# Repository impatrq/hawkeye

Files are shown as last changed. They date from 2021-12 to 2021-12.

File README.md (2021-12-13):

<div align="center">
  
  

</div>

## ¿Que es Hawkeye?
  **Hawkeye** es un sistema desarrollado para asistir a la detección temprana de focos de incendios forestales a través del patrullaje de una flota de drones autónomos.

## ¿De donde surje Hawkeye?
  Este nace de la excesiva cantidad de territorio argentino incendiado el año pasado (2020), el cual superaba las **1.1 millones de hectareas**.
  
## ¿Como Funciona Hawkeye?
  Gracias a un sistema de transimision de datos via **Wi-Fi**, sus multiples **sensores** y su eficaz **aplicacion Android**. Todos estos se combinan de forma correcta para transmitir al usuario la alerta de fuego de la forma mas rapida posible.
  
## Reconocimientos
  Orgullosos de haber ganado el 🥈2do lugar🥈 en la competencia **PROAMBIENTE** de la Universidad Blas Pascal
  Certificado

## Contactanos
  * 📷 Instagram ➔ [Hawkeye Project](https://www.instagram.com/hawkeye.project/)
  * 🖥 Pagina Web ➔ [https://hawkeye-project.glitch.me/](https://hawkeye-project.glitch.me/)
  * ▶️ YouTube ➔ [Hawkeye Project](https://www.youtube.com/channel/UCOA-7zA83bXrav8Rf2SUFfQ)
  * 📧 Correo ➔ hawkeyeproyectimpa@gmail.com

**Desarrolladores:**
  - Garabato, Franco ➔ 📧 Correo: garabato1069@gmail.com
                     ➔ 📷 Instagram: [fran_garabato](https://www.instagram.com/fran_garabato/)
  - Orellano, Uriel ➔ 📧 Correo: uriel.ore9@gmail.com
                    ➔ 📷 Instagram: [awsxyz](https://www.instagram.com/awsxyz/)
  - Palacios, Zhang Lin ➔ 📧 Correo: zlpalacios@hotmail.com
                        ➔ 📷 Instagram: [zhanglinpalacios](https://www.instagram.com/zhanglinpalacios/)
  - Sala, Agustín ➔ 📧 Correo: agustinsala-maxi@outlook.com
                  ➔ 📷 Instagram: [agus_maxi_sala](https://www.instagram.com/agus_maxi_sala/)
  - Solís, Nicolás ➔ 📧 Correo: nikoletto777760@gmail.com
                   ➔ 📷 Instagram: [niko_solis9](https://www.instagram.com/niko_solis9/)
  - Villaescusa, Valentino ➔ 📧 Correo: gannival13@gmail.com
                           ➔ 📷 Instagram: [valen.uwu.18](https://www.instagram.com/valen.uwu.18/)

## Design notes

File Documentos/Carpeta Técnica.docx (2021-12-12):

Proyecto Hawkeye

Carpeta técnica

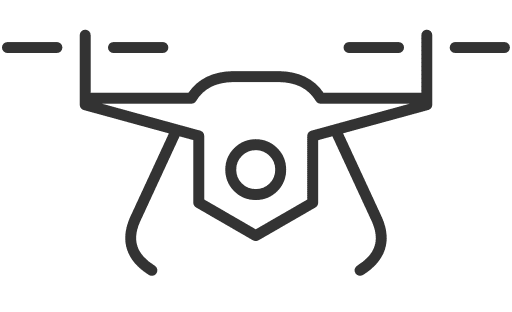
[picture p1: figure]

E.E.S.T. N°7 “IMPA”

Integrantes:

- Garabato, Franco Sicnic
- Orellano, Uriel
- Palacios, Zhang Lin Daoiz
- Sala, Agustin Maximilliano
- Solis, Nicolas
- Villaescusa, Valentino

Profesores a cargo:

- Bianco, Carlos Cesar
- Medina, Sergio
- Carlasara, Fabrizio
- Züge, Magalí
- Alegre, Marcos

Índice:

1. Introducción

1.1: Objetivo del proyecto

1.2: Descripción general

1.3: Diagrama en bloques

1.4: Funcionamiento

2. Componentes:

2.1: Microcontrolador ESP32
2.2: Bateria LiPo

2.3: Motores Brushless

2.4: Módulo GPS

2.5: Sensores MQ

2.6: Cámara térmica

2.7: Módulo transceptor NRF24L0

3. Software:

3.1: Arduino
3.2: Proteus

3.3: AutoCAD 3D

3.4: Cura WEEDO

3.5: Android Studio

4. Modelos 3D:

4.1: Introducción

4.2: Diseño completo del dron

5. Circuitos y plaquetas:

5.1: Placa de recolección de datos y transmisión del Drone
5.2: Placa de recepción y decodificación

5.3: Baliza de Localización Auxiliar

Introducción

1.1: Objetivos del proyecto

Sistema de detección prematura de focos de incendio

Es un proyecto totalmente diseñado y construido por los alumnos, utiliza un drone como plataforma para transportar sensores que sensan y detectan en forma temprana focos de incendio en bosques, sierras y reservas forestales con la finalidad de combatirlos en forma temprana para evitar incrementos en su letalidad y propagación.

A tal efecto se utilizaron sensores de Co, Co2, humo así como también cámaras para visualizar los focos de incendio.

Conforman una red de patrullaje y se utilizan balizas Receptoras-Transmisoras de las señales de alerta que se recuperan de los sensores.

De esta forma, se alerta e informa sobre el estado a un guardia o controlador a cargo de supervisar el escuadrón de drones, con el fin de fomentar la protección del medio ambiente, previendo posibles incendios y ayudando a los especialistas con un reconocimiento previo de la zona e información valiosa sobre la situación.

1.2: Descripción general

El proyecto Hawkeye fue diseñado y llevado a cabo por alumnos del IMPA. Se logró llevar a cabo un prototipo de uno de los drones que formarán parte de la flota vigilante, cuya estructura consta de una parte impresa en 3D y otra hecha en fibra de carbono. Utiliza una placa controladora (programada en Cleanflight) de la marca E-Flight, la cual controla los rotores del mismo por un protocolo PWM a una frecuencia de 50Hz. La placa actúa según lo que recibe por 5 canales de entrada (potencia, Pitch, Roll, Yaw y canal de control) los cuales funcionan con el mismo protocolo. Lo que se realizó para hacer el dron autónomo fue poner un paso antes de entregar los valores que da el receptor de RF. Antes de la placa Skymaster 32 se encuentran un sistema de control de automatización o vuelo manual y un ESP32 encargado de generar los pulsos PWM de acuerdo a la dirección que debe tomar el dron, siguiendo como referencia su localización geográfica, altitud y ángulo de incidencia.

En el modo manual se utiliza una radio RC de 2.4GHz, utilizada en aeromodelismo. En el modo autónomo, en cambio, el dron escucha al ESP32 el cual recibe las coordenadas de destino desde la aplicación de celular. Una vez recibida, las compara con sus coordenadas actuales (gracias a su módulo GPS) mediante algoritmos complejos, y dirige el dron a las nuevas coordenadas, teniendo de referencia su velocidad, altitud y ángulo de incidencia.

1.3: Diagrama en bloques

Transmisor del dron

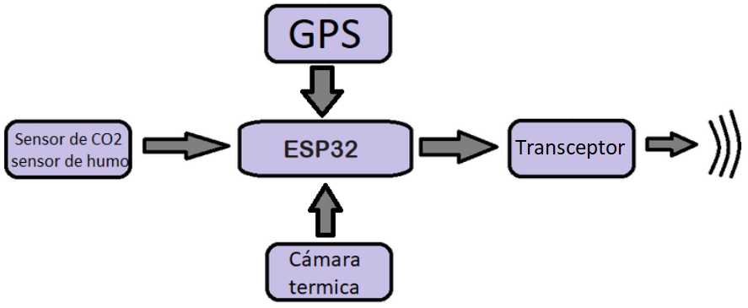
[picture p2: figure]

Receptor de tierra

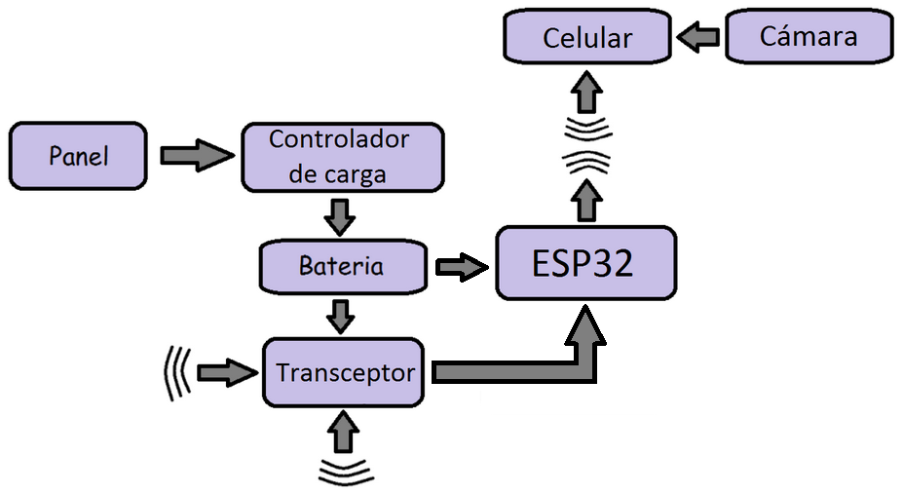
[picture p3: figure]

1.4: Funcionamiento Básico

El funcionamiento del dron es muy complejo, debido a esto lo dividimos en varios sectores:

- Funcionamiento del selector de modo (Manual y Autónomo)

Por medio de un transistor y el ESP32 es posible saturarlo o ponerlo en estado de corte para permitir o no el control a través de la radio RC. De esta forma, se puede seleccionar si recibe la información de control desde un micro, o desde la radio.

- Funcionamiento del sistema GPS

El sistema GPS es utilizado para saber datos como: el rumbo, altitud, velocidad y posición geográfica del dron. Esto nos sirve para que el operario tenga mayor control sobre el dron, para conocer la ubicación de los focos de incendio detectados y para designar el área de trabajo de la flota de drones.

- Funcionamiento del magnetómetro, giróscopo y acelerómetro

El magnetómetro indica la posición del eje longitudinal del drone con respecto al norte magnético y así saber hacia qué dirección debe dirigirse el dron. El giróscopo y acelerómetro se usan para corregir el efecto TILT.8.

- Funcionamiento del sistema de aterrizaje

Cuando se quiera aterrizar, se inicia el protocolo de aterrizaje, se detectará la distancia entre el dron y el suelo y si está en el rango ultrasónico el dron empieza a disminuir la altura lentamente y al aproximarse a unos 5cm-15cm al suelo apagará los motores lentamente para lograr un aterrizaje lo menos forzoso posible.

- Funcionamiento de la comunicación

Se utilizan 2 ESP32 para realizar la comunicación entre el dron y la app en tierra. El ESP en el drone posee un módulo transceptor NRF2401 a 2.4GHz el cual se comunicará con otro igual en tierra. El ESP en tierra recibe los datos del drone por medio del transceptor y luego los transmite por una red wifi que genera a un celular, con una aplicación especialmente diseñada para interpretarlos y mostrarlos al usuario. Los transceptores poseen un rango de funcionamiento de entre 1Km y 1.5Km, con una frecuencia de funcionamiento de 2.4GHz y capacidad telemétrica.

- Funcionamiento del sistema de detección de fuego

El sistema de detección de fuego consta de una serie de sensores capaces de detectar la presencia de un foco en diversas circunstancias. El sensor más obvio es uno de humo, cuyo objetivo no requiere mucha explicación. El segundo es un sensor de Co2, cuyo objetivo es detectar desbalances en el aire en lo que a partes por millón de Co2 respecta, y así poder presuponer la presencia de fuego. Por último, se posee una cámara termográfica, capaz de diferenciar calor a través de varios obstáculos, diurna o nocturnamente.

- Funcionamiento del sistema de avisos

En caso de detectar la presencia de fuego, automáticamente se envía una señal de alerta a la aplicación en tierra con todos los datos recolectados, indicando el dron que lo detectó, su situación geográfica e intensidad del incendio, así como imágenes y video a modo de reconocimiento de la zona.

- Seguridad

Para tener control sobre el estado de los drones se disponen de varios sistemas de seguridad. Por un lado, la parte, aunque parezca insignificante, más crítica es el nivel de batería. El drone está constantemente controlando el nivel de batería y prediciendo el tiempo antes de su descarga, para poder regresar automáticamente en caso de un nivel crítico. Por otro lado, se puede dar un accidente, ya sea por un mal funcionamiento como una colisión, para eso el dron está constantemente transmitiendo a tierra, y en caso de no reportarse después de un tiempo definido se supondrá un accidente y alertará al operador.

- Funcionamiento sistema de búsqueda

Si el dron fue accidentado pero sigue alimentándose, su GPS ayudará a la búsqueda. Pero en caso de no seguir activo, se dispone de un sistema auxiliar que es capaz de detectar impactos y accionarse de forma independiente a los demás sistemas del drone, generando señales audiovisuales para asistir su búsqueda.

- Funcionamiento de la estación de tierra

La estación en tierra es no solo la encargada de recompilar los datos de la flota de drones sino de también hacer de estación de carga. Esto lo logra mediante un panel solar y batería de gel consecuentemente. Esta batería de gel alimenta el sistema de recepción y generación de redes, así como una plataforma de carga para el drone y sus subsistemas.

Componentes

2.1: ESP32

Tenemos 2 ESP32 los cuales se usan para la comunicación entre la aplicación del celular y los sensores. Estos microcontroladores son creados por la multinacional Expressif Systems, forma parte de una serie de system on chip (SoC) y son módulos de bajo coste y consumo capaz de soportar Wi-Fi y Bluetooth. Los microprocesadores son de 32-bits que puede ser Dual Core o Single Core

Características del microcontrolador:

3 x SPI

2 x I2S

12 x ADC input channels

2 x DAC

2 x I2C

10x capacitive touch interface

Procesador doble núcleo de 240MHz

520 KB SRAM

16MB Flash

802.11BGN HT40 Wi-Fi

2.2: Batería LiPo

La batería es clave para el funcionamiento del cuadricoptero. Es quien alimenta los ESP, motores, módulo E-Sky y receptor.

Lo más difícil fue encontrar una batería que cumpla con nuestras necesidades, ya que mientras más pese, menos va a poder volar el dron y más difícil se hará controlarlo.

Finalmente se eligió una batería LiPo de 2200mAh 3S (11,1V). Debido a su eficacia a la hora de alimentar al cuadricóptero se la consideró la mejor opción

Características de la batería:

- Capacidad:2200mAh
- Descarga continúa: 25C
- Corriente continúa Máxima: 50a
- Celdas: 3S1P
- Peso: 150g
- Ficha de descarga

El tener 3 celdas significa que la batería tiene 3 "mini baterías" conectadas en serie, cada una tiene 3,7V.

Se recomienda evitar salir del rango 3,5V-4,2V para evitar que la batería se dañe

La batería al tener bajo peso no supone un gran impacto sobre el cuadricoptero.

La batería provee un aproximado de 20 minutos de vuelo.

2.3: Motores Brushless

El motor Brushless es un motor eléctrico que no emplea escobillas para realizar el cambio de polaridad en el rotor. Los motores eléctricos solían tener un colector de delgas o un par de anillos rozantes. Estos sistemas producen rozamiento, disminuyen el rendimiento, desprenden calor y ruido y requieren de mucho mantenimiento, además pueden producir partículas de carbón que manchan el motor de polvo que puede también ser un conductor.

Se utilizó el motor CF2822 ya que se adapta perfectamente a las exigencias de nuestro proyecto. Es económico y fácil de conseguir.

Poseen altas revoluciones y funcionan con energía trifásica.

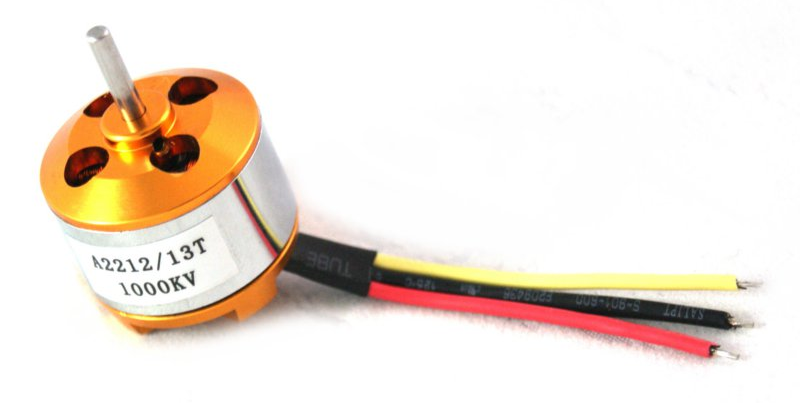
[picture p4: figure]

Características:

- Peso: 39g
- Eje: 3 mm
- Longitud: 47mm
- Diámetro: Tamaño del estator:22x10mm
- Hélices: 8x7 - 10x5
- Voltaje: 2s - 3s
- Corriente máxima: 16.5A
- Kv: 1200
- Empujé máximo: 850g

Por lo tanto el cuadricóptero tiene un empujé marino de 3400g, teniendo en cuenta que la estructura pesa X, se podría decir que el cuadricoptero es capaz de llevar carga de hasta X

Por otro lado 1200kv significa que por cada Volt inyectado al motor, este realiza 1200 rpm. Es decir que con una alimentación de 11,1V el motor podría llegar hasta 13320 rpm en un caso extremo. Normalmente la cantidad de revoluciones es de 7000 a 8000 rpm en un vuelo tranquilo

A este motor se le recomiendo usar propelas 1045 ya que la relación fuerza/velocidad es la mejor.

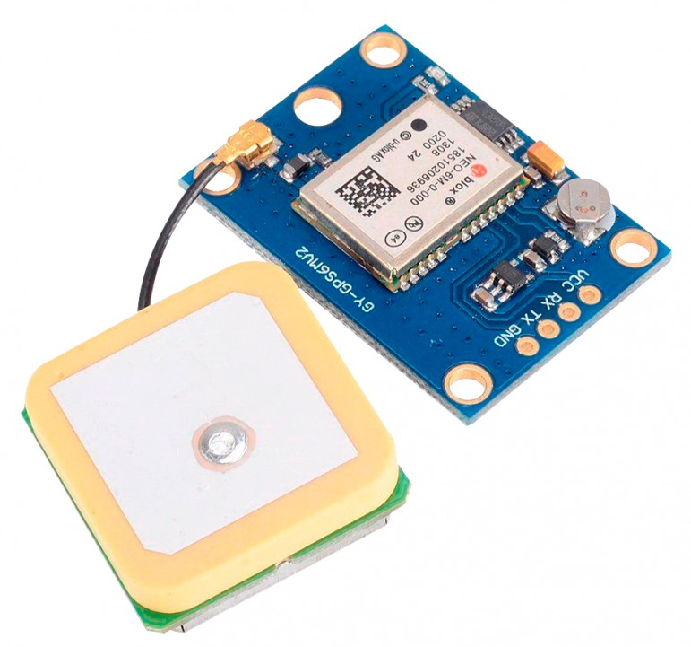
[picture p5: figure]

2.4: Módulo GPS

El módulo GPS que estamos usando se trata de un GY-NEO6MV2, que trabaja a 3,3V. utiliza el protocolo de transmisión SLI.

Entre sus características destacamos que tiene una precisión que ronda los 5 M además de que es capaz de brindar datos como Altitud, longitud, latitud, fecha y hora.

Decidimos incluir un módulo GPS no solo para saber la ubicación del dron y fomentar su autonomía, sino también para poder ubicarlo en el caso que tenga algún incidente durante el vuelo y se acabe perdiendo.

2.5: Sensores MQ

Los sensores MQ son electroquímicos, esto quiere decir que cuando se exponen a determinados gases su resistencia variará internamente, cuenta con un calentador encargado de incrementar la temperatura interna para que el sensor pueda reaccionar a los gases, y por consecuencia, cambiar el valor de la resistencia. El calentador requiere de entre 2 V a 5V. El sensor se comporta como una resistencia y a su vez necesita de una resistencia de carga para cerrar el circuito con el fin de hacer un divisor de tensión y poder leerlo desde el microcontrolador.

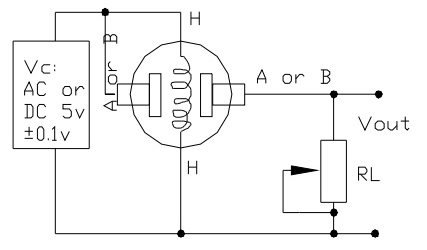
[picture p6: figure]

Debido al calentador es necesario esperar un tiempo de calentamiento que varía entre las 12 y las 48 horas. esto se hace para que la salida sea estable y tenga las características que el fabricante muestra en sus datasheet

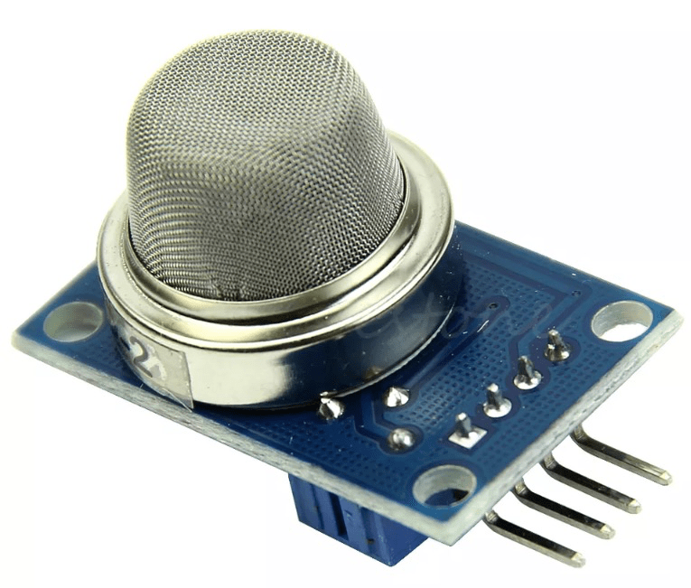
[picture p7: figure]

2.5.1: MQ2

Utilizamos el sensor MQ2 principalmente para poder detectar el humo que genera el fuego, aunque también se puede usar para detectar GLP, propano, metano, alcohol e hidrógeno.

2.5.2: MQ 135

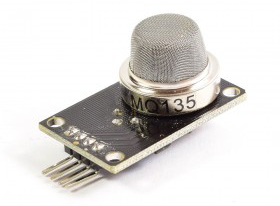
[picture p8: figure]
Sensor Calidad Aire MQ135

Se utilizan en equipos de control de calidad del aire para edificios y oficinas, son adecuados para la detección de NH3, NOx, alcohol, benceno, humo, CO2, etc. Este último sensor es sensible en similar proporción a los gases mencionados, con lo que podemos determinar si el aire está limpio.

2.6: Cámara térmica

Se utiliza una cámara termográfica para detectar la presencia de calor. La cámara está calibrada para ver la radiación infrarroja, generada por todo objeto, cuyo valor puede ser detectado y visualizado con colores. El dron utiliza esta cámara para detectar una fuente de calor por encima de 60 grados centígrados. En nuestro caso, nuestro límite es superior para asegurarnos de que es un foco de incendio, y no una piedra calentada por el sol o un animal..

2.7: Módulo transceptor NRF24L01

Dos módulos transceptores NRF24L01 son la clave para la comunicación inalámbrica, son de tamaño compacto, banda de 2,4 GHz y puede operar con velocidades de transmisión de 250 kbps hasta 2 Mbps, con un alcance de 1 Km entre los mismos. El voltaje de operación de los módulos es de 1,9 a 3,6V y la corriente durante la transmisión es de 11.3mA y de recepción es de 13.5mA @ 2 Mbps, 900 nA en power down y 26 uA en standby.

Características:

Pines: MOSI, MISO, SCK, IRQ, CSN, CE, VCC y GND.

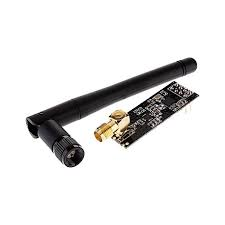
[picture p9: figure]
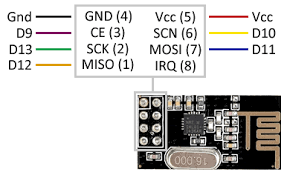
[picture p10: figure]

Software

3.1: Arduino:

Arduino es un software que permite escribir código y compilarlo para su aplicación a un microcontrolador. Arduino también posee sus propias plaquetas con microcontroladores, si bien no fueron usadas en este proyecto debido a sus limitaciones tecnológicas. El objetivo detrás de Arduino era crear una plataforma para crear proyectos electrónicos, tanto en el aspecto de la programación como el de los componentes y conexiones.

En este software programamos en un lenguaje especial que es Java en un entorno de wiring con algunas funciones de C++ a los ESP32 para la comunicación y la transmisión y recepción de datos de sensores con el celular. Si bien nuestra preferencia y campo de trabajo preferidos es Python y MicroPython, en esos entornos no se encuentran librerías que nos permitan controlar los sensores, por lo que nos habría llevado más tiempo de lo que disponíamos, ya que tendríamos que crear las nuestras. Por ende se decidió usar arduino que, si bien tiene muchas limitaciones, gracias a su popularidad posee centenares de librerías.

3.2: Proteus:

Proteus es un software para diseñar e imprimir plaquetas microcontroladoras, posee interfaces de prueba para simular el conjunto de componentes, así como una interfaz para diseñar PCBs.

3.3: AutoCAD:

AutoCAD se utiliza para desarrollar planos, diseños y modelos 3D, en el caso del proyecto Hawkeye, lo utilizamos para modelar el cuerpo del dron, sus partes y sus componentes, y así poder realizar las impresiones en 3D de las partes.

3.4: Cura WEEDO:

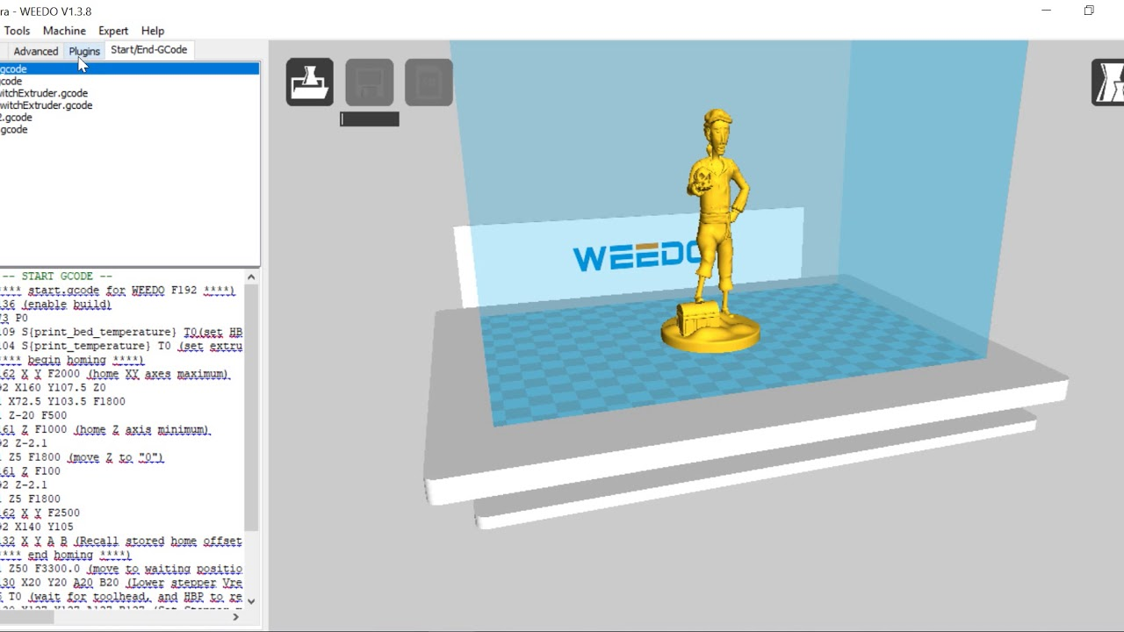
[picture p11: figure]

Cura WEEDO es un programa específicamente diseñado para impresoras 3D con el fin de acomodar la pieza en el espacio de manera que se puedan evitar problemas durante la impresión. Asimismo permite generar un archivo de impresión reconocible por una impresora 3D.

3.5: Android Studio:

Android Studio es una app basada en Java para crear aplicaciones de celular, esta posee una interfaz gráfica para crear las apps, lo cual la hace intuitiva y sencilla de utilizar.

Modelos 3D

Introducción

Los modelos 3D fueron desarrollados con el software de Autodesk, AutoCAD. Este cuenta con excelentes herramientas para el diseño tanto 2D como 3D. Gracias a la licencia estudiantil pudimos utilizarlo de manera oficial en su versión 2019

Para llevar a la realidad los diseños primero se exportaron los archivos CAD (.dwg) a un formato aceptado por la impresora (.stl), luego se importaban al programa Cura WEEDO y se exportaba nuevamente para poder imprimirse

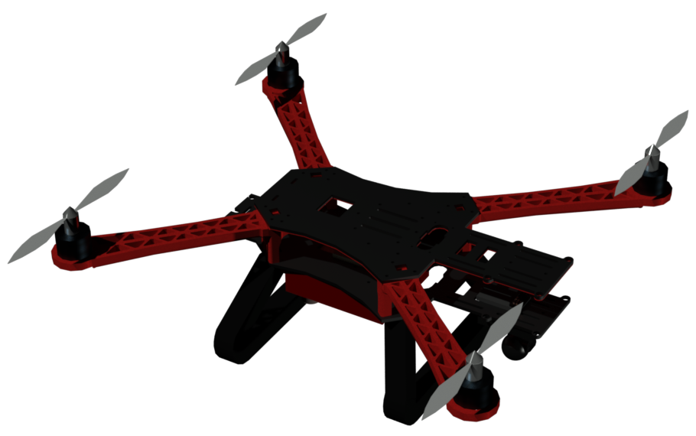
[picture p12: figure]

Circuitos Esquemáticos y PCBs

Introducción

Los esquemáticos y su traslado a PCB fue realizado en Proteus, programa desarrollado por LabCenter Electronics que permite realizar dichas acciones con mucha facilidad. Primero se desarrollaron los circuitos en formato esquemático. Con el diseño ya corroborado se armaron los PCB, imprimieron y llevaron a la realidad, con hojas termotransferibles, una plancha y cloruro férrico. Con las pruebas de los primeros prototipos realizadas, se hicieron las correcciones e imprimieron las placas finales.

5.1 Placa de recolección de datos y transmisión del Drone:

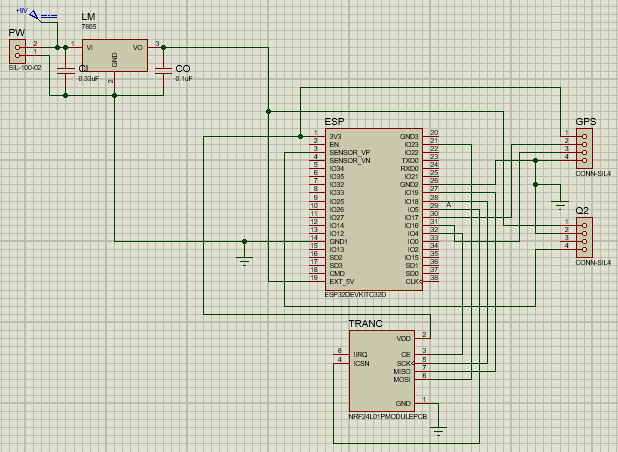
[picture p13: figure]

El fin de esta placa es recolectar los datos de los sensores y generar la conexión con tierra para transmitir los datos y alertas pertinentes. Además de los módulos ya mencionados consta de un pequeño circuito regulador de tensión para alimentar el sistema con una batería de 9V recargable.

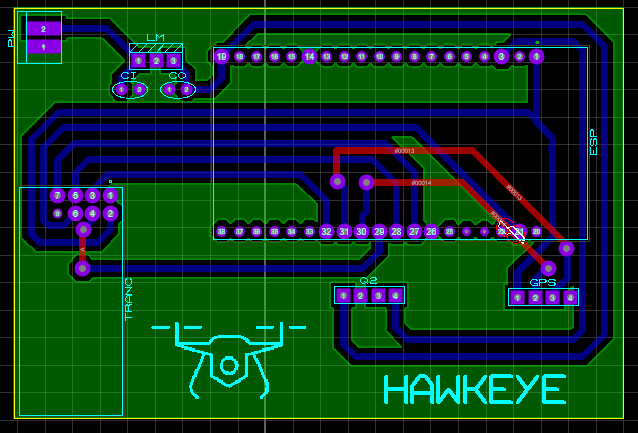
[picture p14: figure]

5.2 Placa de recepción y decodificación

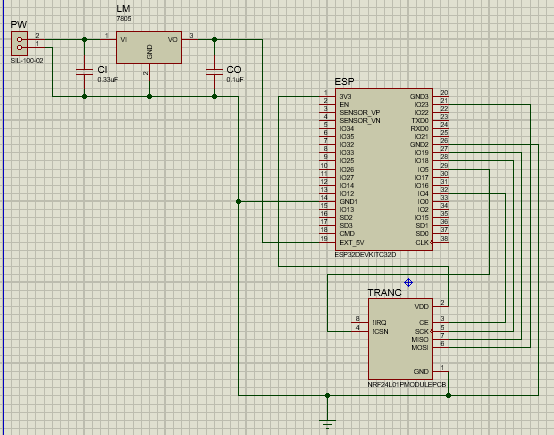
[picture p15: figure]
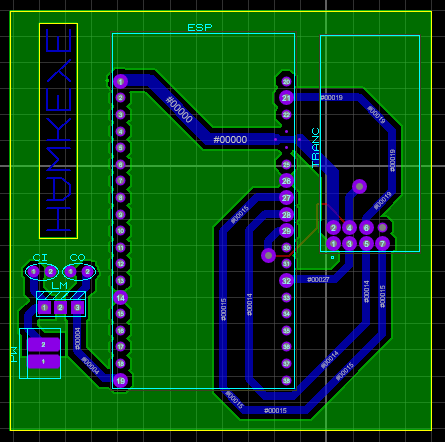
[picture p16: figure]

El objetivo de esta placa es recibir la información de los sensores, decodificarla y transmitirla a un celular o dispositivo inteligente para poder ser interpretado por el usuario. Esta posee un regulador de carga el cual sirve para convertir los 12V provenientes de la batería de gel que la alimenta en 5V. Este apartado posee un panel solar con un regulador de carga para la batería que alimenta el sistema, así como una salida para cargar el drone con energía limpia.

Baliza de Localización Auxiliar

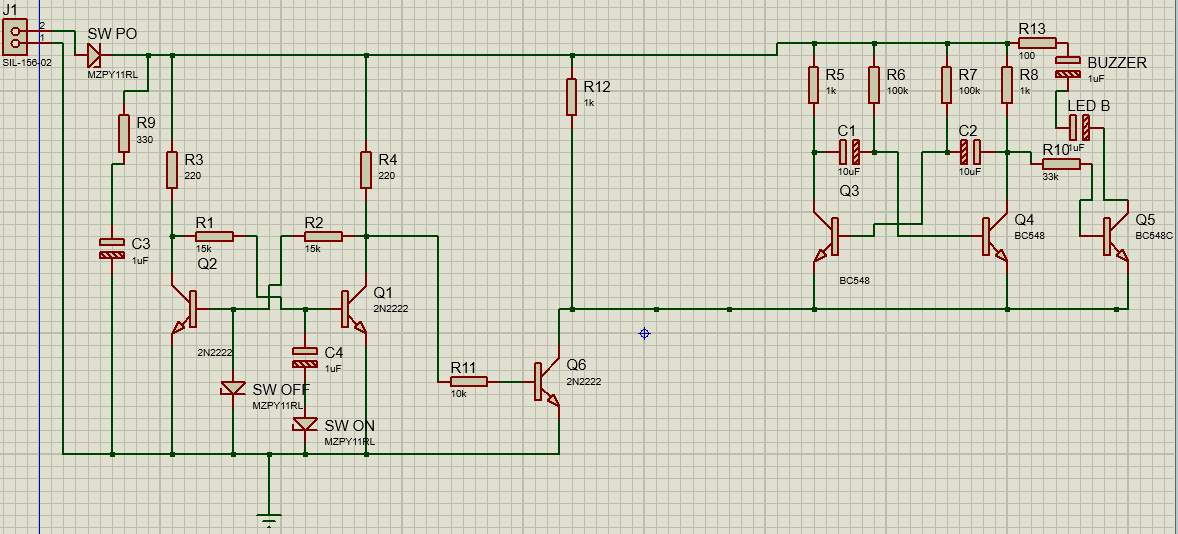
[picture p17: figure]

Esta placa es una combinación de un Biestable con un Astable. Al activarse el sensor de TILT con un golpe, el biestable cambia la rama por la cual envía energía y se mantiene en esta permanentemente. A dicha rama va conectado un transistor, el cual actúa de interruptor para el Astable. Mientras el Astable esté funcionando, se generará una oscilación en un led de alta potencia y un buzzer, que llamaran la atención de una persona en busca del drone.

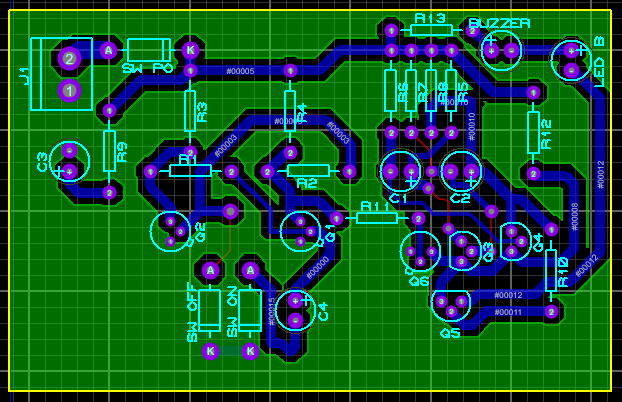
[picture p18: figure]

Proyecto Hawkeye

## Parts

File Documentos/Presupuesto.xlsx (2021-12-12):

7°2° AVC | Proyecto "Hawkeye" | COM C
Cantidad | Componente | Link de referecia | Mejor precio (Por unidad)
Electronica RC:
4 | Buzzer |  | $150.00
8 | Capacitores Electroliticos |  | $10.00
12 | Transistor 2n2222 |  | $20.00
12 | Transistor BC549 |  | $15.00
4 | Led Blanco de alta potencia |  | $30.00
9 | Switch |  | $150.00
 |  |  | Total: $2,570.00
Radian Electronica:
4 | Sensor Tilt |  | $220.00
TodoMicro
1 | Modulo GPS | CLICK (https://www.todomicro.com.ar/investigacion-desarrollo-y-prototipado/339-modulo-gps-gy-neo6mv2-con-antena.html) | $1127.00
1 | Sensor Co2 | CLICK (https://www.todomicro.com.ar/arduino/257-modulo-sensor-de-gas-mq2.html) | $195.00
2 | Modulo Tranceptor | CLICK (https://www.todomicro.com.ar/arduino/312-modulo-transceptor-nrf24l01palna.html) | $704.00
 |  |  | Total: $2,730.00
Mercado Libre: (Ambos productos del mismo proveedor, para envio gratis)
2 | ESP32 | CLICK (https://articulo.mercadolibre.com.ar/MLA-916790826-nodemcu-esp32-wifi-bluetooth-42-iot-wroom-esp32s-arduino-_JM) | $1195.00
4 | Servos | CLICK (https://articulo.mercadolibre.com.ar/MLA-916790826-nodemcu-esp32-wifi-bluetooth-42-iot-wroom-esp32s-arduino-_JM) | $287.00
1 | Receptor Flysky | CLICK (https://articulo.mercadolibre.com.ar/MLA-932512724-receptor-flysky-fsia10b-ppm-rc-drone-avion-auto-_JM) | $8999.00
2 | Fichas Conectores Xt-60 | CLICK (https://articulo.mercadolibre.com.ar/MLA-863802387-fichas-conectores-xt-60-x-par-macho-hembra-_JM) | $349.00
1 | Helice 11x6 | CLICK (https://articulo.mercadolibre.com.ar/MLA-928114827-11x6-apc-original-usa-glow-_JM?variation=89819360933) | $1958.00
1 | Cable Extension Servo | CLICK (https://articulo.mercadolibre.com.ar/MLA-916710267-cable-extension-fina-y-de-servo-300mm-tipo-futaba-_JM) | $385.00
1 | Helice 9x5 | CLICK (https://articulo.mercadolibre.com.ar/MLA-934611714-helice-emax-electrica-9x5-_JM?variation=94594494561) | $385.00
1 | Tubo Siliconado | CLICK (https://articulo.mercadolibre.com.ar/MLA-856240680-tubo-siliconado-trasnparente-glow-x-metro-2mm-x-5mm-_JM) | $628.00
Total: |  |  | $22078.00
Alumnos:
 | Franco Garabato Sinic
 | Valentino Villaescusa
 | Zhang Lin Daoiz Palacios
 | Nicolás Ignhacio Solís
 | Agustin Sala
 | Uriel Orellano
Datos Adicionales:
 | Link TodoMicro: https://www.todomicro.com.ar/

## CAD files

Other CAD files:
Modelados 3D/Cubre sensores.dwg
Modelados 3D/Modelo 3D Drone.dwg
Modelados 3D/Drone con placas .dwg
Modelados 3D/Placa + Cubre.dwg

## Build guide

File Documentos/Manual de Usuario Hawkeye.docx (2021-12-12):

Manual de usuario

Proyecto Hawkeye


Índice:

1. INFORMACIÓN GENERAL

1.1. Descripción General ……………………………………………………… 2

1.2. Finalidad del proyecto …………………………………………………… 2

2. OPERACIÓN

2.1. Preparación y chequeos previos …………………………………. 3

2.2. Encendido ………………………………………………………………………. 4

2.3. Operación ………………………………………………………………………. 4

2.4. Aplicación ………………………………………………………………………. 5

3. MANTENIMIENTO

3.1. Batería …………………………………………………………………………... 8

3.2. Uso del cargador …………………………………………………………. 10

3.3. Estructura ………………………………………………………………….…. 11

4. PRECAUCIONES

4. Precauciones ………………………………………………………………….. 12

      1. INFORMACIÓN GENERAL
  1.1. Descripción General

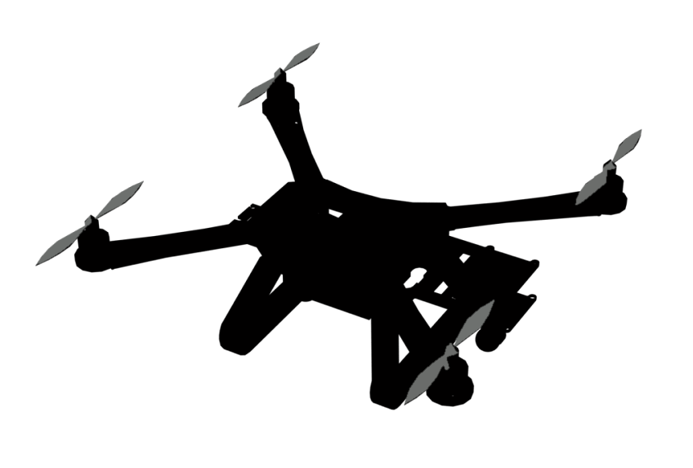
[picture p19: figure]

Este proyecto consiste en la ayuda a la temprana detección de focos de incendio forestales, a través de la utilización de un sistema avanzado de red de protocolo de drones automatizados. Mediante una versátil app, diseñada con sencillez en mente, Hawkeye pretende convertirse en la alternativa más económica y eficaz a la asistencia a dicha tarea en el mercado.

  1.2. Finalidad del Proyecto

Se busca la utilización de Hawkeye por parte de empresas y/u organizaciones de tipo auxiliares a las problemáticas ambientales. Es el fin del proyecto proteger el ambiente en el que vivimos de forma segura y afable. A través de una escuadra de cuatrirrotores completamente equipados con sensores para la detección de incendios, el objetivo de Hawkeye es alertar al usuario ante cualquier indicio de origen de un potencial foco de incendio.

      2. OPERACIÓN

2.1. Preparación y chequeos previos

Antes de comenzar a utilizar el dron se debe contar con las siguientes aptitudes:

- Tener conocimiento sobre la utilización del joystick.
- Ser conscientes de nuestras capacidades.

A continuación, verificar las siguientes cuestiones:

- Verificar la correcta conexión de todos los componentes, además de su integridad.
- Verificar el ajuste y correcta colocación de todos los tornillos y tuercas.
- Verificar que las pilas del control estén cargadas.
- Verificar que la batería esté cargada.
- Observar y evaluar si las condiciones climáticas no son desfavorables (ejemplos: mucho viento, lluvia, niebla que disminuya la visión, etc.)
- Verificar la integridad y correcta disposición de las hélices.
- Asegurar que el dron se encuentre sobre una superficie lo más plana posible.
- Verificar que ambas palancas del control estén ubicadas en el centro.

Una vez realizada esta inspección, estaremos en condiciones de encender el dron.

2.2. Encendido

Los pasos a seguir para encender el dron son:

1) Encender el radio control, veremos una luz verde encendida en el centro por debajo del control.

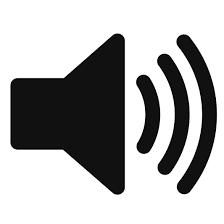
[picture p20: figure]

2) Conectar la batería al dron, asegurando el sonar de 3 pitidos.
3) Encender y/o conectar la alimentación de las plaquetas (pilas y baterías).
4) El dron debería ser visible para vincular con la aplicación en la pestaña “Vincular”.

2.3. Operación

Para volar el dron se deberá procurar estar a una distancia NO menor a 15 metros para arrancar los motores.

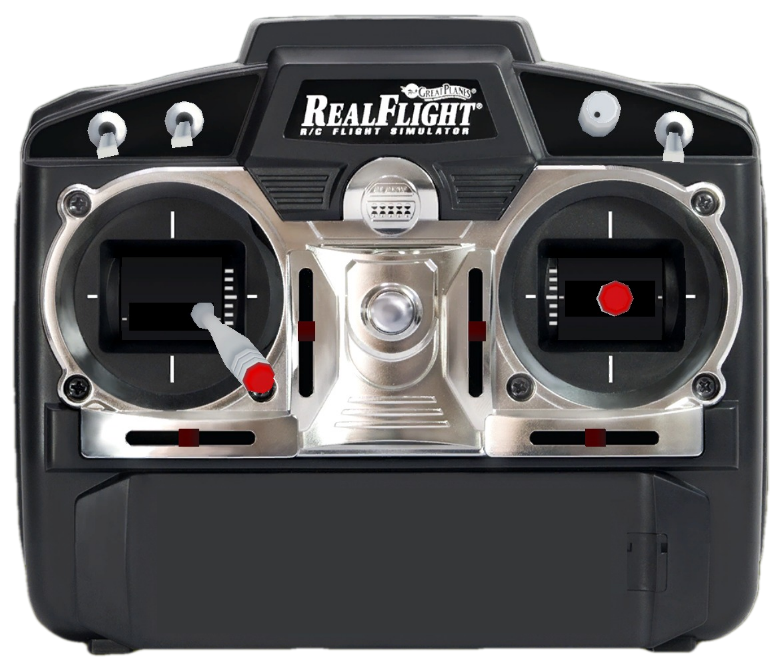
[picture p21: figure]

Para poner los motores en condición de arranque, es necesario tirar la palanca izquierda del joystick hacia abajo y a la derecha como lo muestra la imagen:

Una vez que los motores se encuentren encendidos, ubicar la palanca izquierda nuevamente en el centro.

Luego, elevar el dron sucesivamente hasta una altura mínima de 10 metros. En este momento, accionar el modo de vuelo autónomo desde la aplicación, tappeando en el botón de Modo Automático.

2.4. Aplicación

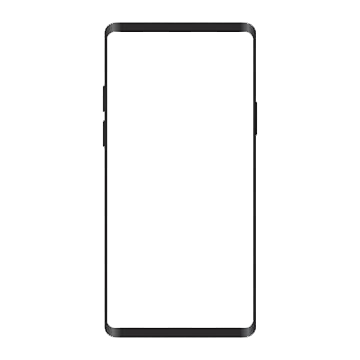
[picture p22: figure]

1) Descargar aplicación de la página de Hawkeye o de la Play Store.

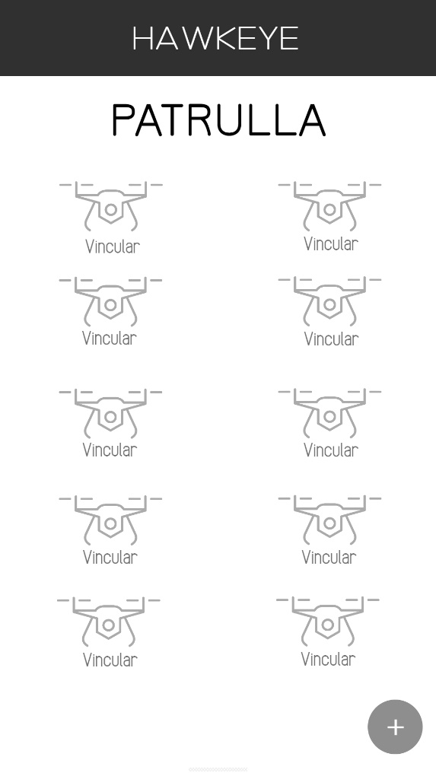
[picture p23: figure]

2) Ingresar a la aplicación y tocar el botón de “+”.
3) Vincular el dron.

Página

Principal

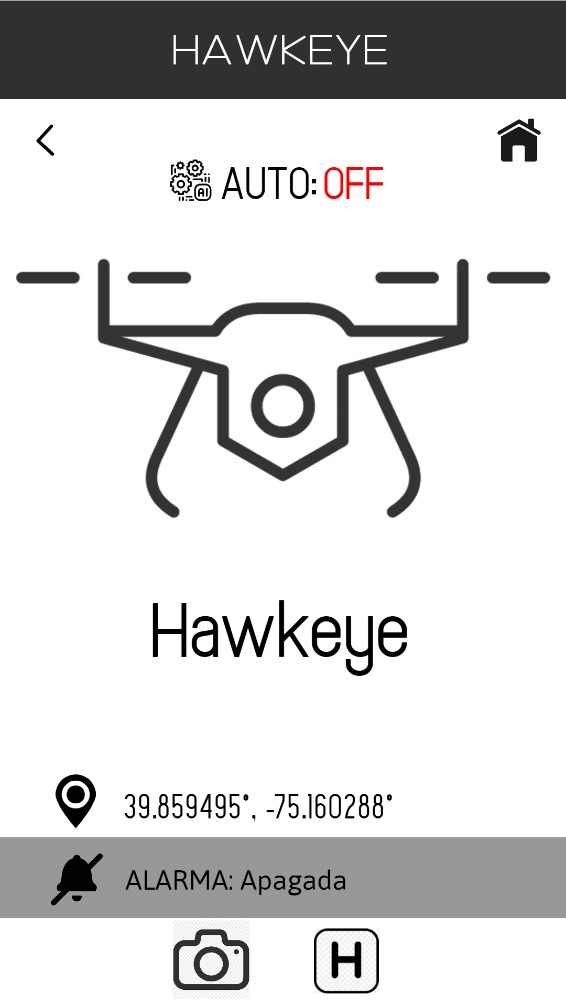
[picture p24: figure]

Volver

Indicador de

batería del dron

Modo Automático

Posición

Geográfica

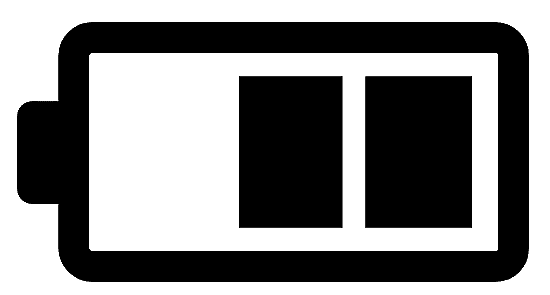
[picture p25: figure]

Nombre asignado al dron

Alarma de Detección de Incendio

Cámara del dron

Retorno Automático

Página principal: Retornar a la página principal de la aplicación,

Volver: Retornar a la anterior pestaña de la aplicación.

Indicador de batería del dron: Indicador de la batería restante del dron vinculado.

Modo Automático: Activar el modo autónomo del dron / trazar ruta de patrullaje.

Posición Geográfica: Posición actual geográfica del dron.

Nombre asignado al dron: Nombre asignado al dron al vincularlo a la aplicación.

Alarma de Detección de Incendio: Estado de alarma del Sistema de Detección de Incendio.

Cámara del dron: Cámara en vivo del dron.

Retorno automático: Retorno automático del dron al punto definido como “Base” al vincular.

3. MANTENIMIENTO

3.1. Batería

Cada vez que se termina de utilizar el dron se deben realizar los siguientes pasos dependiendo el caso:

1) Si se volará nuevamente el dron:
- Detener los motores.
- Desconectar la batería.
- Desconectar alimentación de plaquetas.
- Apagar el control.
- Poner la batería a cargar.
- Esperar a que esté completamente cargada.
- Desconectar el cargador de la batería.
- Comenzar nuevamente con el procedimiento de encendido y automatización del dron.
2) Si no se volará nuevamente el dron:
- Detener los motores.
- Desconectar la batería.
- Desconectar alimentación de plaquetas.
- Apagar el control.
- Enchufar la batería al cargador.
- Colocar la batería en modo MANTENIMIENTO.
- Esperar a que la batería llegue a su nivel de mantenimiento.
- Desconectar el cargador.
- Guardar batería.

Para iniciar el modo mantenimiento se debe:

- Conectar el cable de alimentación del cargador a una fuente de entre 14V y 19V.
- Conectar el cable de la batería al cargador (conector de 4 entradas).
- Encender la fuente.
- Pulsar el botón “Batt Type” hasta que aparezca en la pantalla LiPo.
- Pulsar el botón “Start”.
- Con los botones “Dec” e “Inc”, ir cambiando hasta encontrar el modo Storage.
- Con el botón “Batt Type” se pueden cambiar los parámetros de carga. Se recomienda una corriente de carga de 5A.
- Pulsa el botón “Start” durante 3 segundos hasta que se escuche una serie de pitidos.
- Si la verificación de celdas que aparece en pantalla es correcta pulsar “Start” para comenzar la carga.
- Cuando termine, sonará un pitido y se detendrá la carga. Apagar la fuente y desconectar los cables de la batería, procurando la inexistencia de un cortocircuito.

3.2. Uso del Cargador

Para realizar una carga balanceada:

- Conectar el cable de alimentación del cargador a una fuente de entre 14V y 19V.
- Conectar el cable de la batería al cargador. Cable “dean t” a “banana”.
- Conectar el cable de la batería al cargador (conector de 4 entradas).
- Encender la fuente.
- Pulsar el botón “Batt Type” hasta que aparezca en la pantalla LiPo.
- Pulsar el botón “Start”.
- Con los botones “Dec” e “Inc”, ir cambiando hasta encontrar el modo Balanced.
- Con el botón “Batt Type” se pueden cambiar los parámetros de carga. Se recomienda una corriente de carga de 5A.
- Pulsa el botón “Start” durante 3 segundos hasta que se escuche una serie de pitidos.
- Si la verificación de celdas que aparece en pantalla es correcta pulsar “Start” para comenzar la carga.
- Cuando termine, sonará un pitido y se detendrá la carga. Apagar la fuente y desconectar los cables de la batería, procurando la inexistencia de un cortocircuito.

3.3. Estructura

Cada vez que se termina de utilizar el dron es recomendable:

- Revisar que no se haya desconectado anda, para evitar posibles falsos contactos.
- Observar que el dron no tenga ningún daño estructural.

En caso de encontrar un daño grave en alguna parte de la estructura, llámese rotura, falta de alguna pieza, entre otras, realizar los siguientes pasos:

- Verificar que esté desconectada la batería.
- Desarmar lo necesario del dron para remover la parte dañada.
- Buscar un repuesto de la parte dañada, en caso de no tenerlo, buscar los planos e imprimir uno en una impresora 3D o comprarlo.
- Reemplazar la parte dañada una vez que tengamos el repuesto.
- Rearmar el dron.
- Verificar que los tornillos y tuercas queden colocados y ajustados como corresponde.
- Montar nuevamente los elementos desmontados cuando se desarmó de haber sido necesario quitarlos, siempre refiriéndose a los planos de referencia del dron.

4. PRECAUCIONES

- NO volar el dron con mal clima, principalmente evitar vientos fuertes.
- NO volar el dron si la batería tiene menos de 85% de carga.
- Tener a mano repuestos de la estructura (principalmente las hélices). para poder reemplazar las partes dañadas rápidamente en caso de que haya un accidente.
- Tener al menos 5 metros de distancia entre el dron y las personas para evitar accidentes.
- Evitar vuelos innecesarios.
- Tener tornillos y tuercas de repuesto.
- Tener especial cuidado con las partes impresas en 3D.

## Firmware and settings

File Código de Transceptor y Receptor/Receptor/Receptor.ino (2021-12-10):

#include <WiFi.h>
#include <WiFiClient.h>
#include <WiFiServer.h>
#include <WiFiUdp.h>
#include <SPI.h>
#include <nRF24L01.h>
#include <RF24.h>
 
//Declaremos los pines CE y el CSN
#define CE_PIN 4
#define CSN_PIN 5
 
//Variable con la dirección del canal que se va a leer
byte direccion[5] ={'c','a','n','a','l'}; 

//creamos el objeto radio (NRF24L01)
RF24 radio(CE_PIN, CSN_PIN);

//vector para los datos recibidos
float datos[3];

void setup()
{
 //inicializamos el NRF24L01 
  radio.begin();
  //inicializamos el puerto serie
  Serial.begin(9600); 
  
  //Abrimos el canal de Lectura
  radio.openReadingPipe(1, direccion);
  
    //empezamos a escuchar por el canal
  radio.startListening();
 
}
 
void loop() {
 uint8_t numero_canal;
 //if ( radio.available(&numero_canal) )
 if ( radio.available())
 {    
     //Leemos los datos y los guardamos en la variable datos[]
     radio.read(datos,sizeof(datos));
     if (datos[2] == 0)
     {
     //reportamos por el puerto serial los datos recibidos
     Serial.print("Latitud= " );
     Serial.print(datos[0], 6);
     Serial.print(" , ");
     Serial.print("Longitud= " );
     Serial.print(datos[1], 6);
     Serial.print(" , FUEGO!! ");
     Serial.println(datos[2]);
    }
    else
    {
     //reportamos por el puerto serial los datos recibidos
     Serial.print("Latitud= " );
     Serial.print(datos[0], 6);
     Serial.print(" , ");
     Serial.print("Longitud= " );
     Serial.print(datos[1], 6);
     Serial.print(" , ");
     Serial.println(datos[2]);
   }
 }
 else
 {
     Serial.println("No hay datos de radio disponibles");
 }
 delay(1000);
}

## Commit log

2021-12-10 Feat: Crear Esqueleto de la App
2021-12-10 Fix: Borrar Archivos Equivocados
    [GPS.ino, Recepcion.ino, Receptor.ino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]
2021-12-10 Fix: Cambiar la URL a la que nos lleva el boton
2021-12-11 Style: Cambiar Colores de barra de navegacion y Eliminar texto de 2da pantalla
2021-12-11 Style: Cambiar texto e imagenes de la barra inferior
2021-12-11 Fix: Agregar nuevamente las imagenes que no se mostraban
2021-12-11 Fix: Remover Archivos Erróneos
    [GPS.ino, Recepcion.ino, Receptor.ino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]
2021-12-11 Docs: Diagramar División de Trabajo
    [Diagrama Tareas Proyecto.xlsx]
2021-12-11 Docs: Guardar Manual de Usuario
2021-12-11 Docs: Guardar Presupuesto
    [Presupuesto.xlsx]
2021-12-11 Docs: Modelar Dron con Sensores en AutoCAD
    [Drone con placas .dwg]
2021-12-11 Docs: Modelar Dron con Sensores en Maya
2021-12-11 Docs: Modelar Dron en AutoCAD
    [Modelo 3D Drone.dwg]
2021-12-11 Docs: Modelar Carcasa de Sensores
    [Cubre sensores.dwg]
2021-12-11 Docs: Modelar Carcasa con Sensores Incorporados
    [Placa + Cubre.dwg]
2021-12-11 Docs: Modelar Carcasa de Sensores en AutoCAD
    [Cubre sensores.dwg]
2021-12-11 Docs: Modelar Carcasa con Sensores Incorporados en AutoCAD
    [Placa + Cubre.dwg]
2021-12-11 Style: Diseñar base de la Pestaña "Dron"
2021-12-11 Refact: Agregadas nuevas URLs de Imagenes
2021-12-11 Style: Terminar la pestaña "Dron" con Texto e Imagenes
2021-12-11 Fix: Borrar archivos no deseados
    [GPS.ino, Recepcion.ino, Receptor.ino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]
2021-12-11 Feature: Lectura Sensor de Humo
2021-12-11 Fix: Configurar Enter en Consola
    [Receptor.ino]
2021-12-12 Feature: agregar PCB baliza
2021-12-12 Feature: agregar PCB drone
2021-12-12 Feature: agregar PCB estación tierra
2021-12-12 Feature: Agregado de README.md
2021-12-12 Fix; borrado de archivos no deseados
    [Receptor.ino, Tranceptor.ino]
